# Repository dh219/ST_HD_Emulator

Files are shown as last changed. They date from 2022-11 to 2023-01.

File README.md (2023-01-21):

# ATARI ACSI Hard Drive Controller Emulator
Use your ageing ATARI ST again!

KISS principal implemented throughout!

This has been done before. I don't pretend to have invented this. However, this design uses the Raspberry PI PICO, which, at time of designing, had not been done before.

This is in know way the finished article. I have uploaded to git simply because there is some interest, and who knows? maybe others will conribute to make a "complete" package.

### Initial Release:
Both PICO CPU cores are used. Core 2 is solely used for decoding command packets. Core 1, prints command data and live status. 

Note the shell... you can do things whilst the emulator is doing its stuff. At the moment, there isn't much. Just date, time reporting. But partition dumps could be performed, partitioning and formatting sd cards etc.

Revised Hardware design
The TXB0108 part is not suitable for this project. A 74xxx245 part is needed as I used in the prototype. Why oh why did I change it !!!

### Latest Improvements:
* Incorporated local spi and sdcard files and optimised for this project.
* Removed the No-OS-FatFS dependancy.
* Two SD-CARDS are now functional.
* Tested with ICD driver, HDDriver driver, AHDI driver, PPutnik driver.
* Tested with EmuTOS and FreeMint.
Typical transfer speeds are > 900 KB/s and peak just under 1100 KB/s. Dependent upon sd-card used.





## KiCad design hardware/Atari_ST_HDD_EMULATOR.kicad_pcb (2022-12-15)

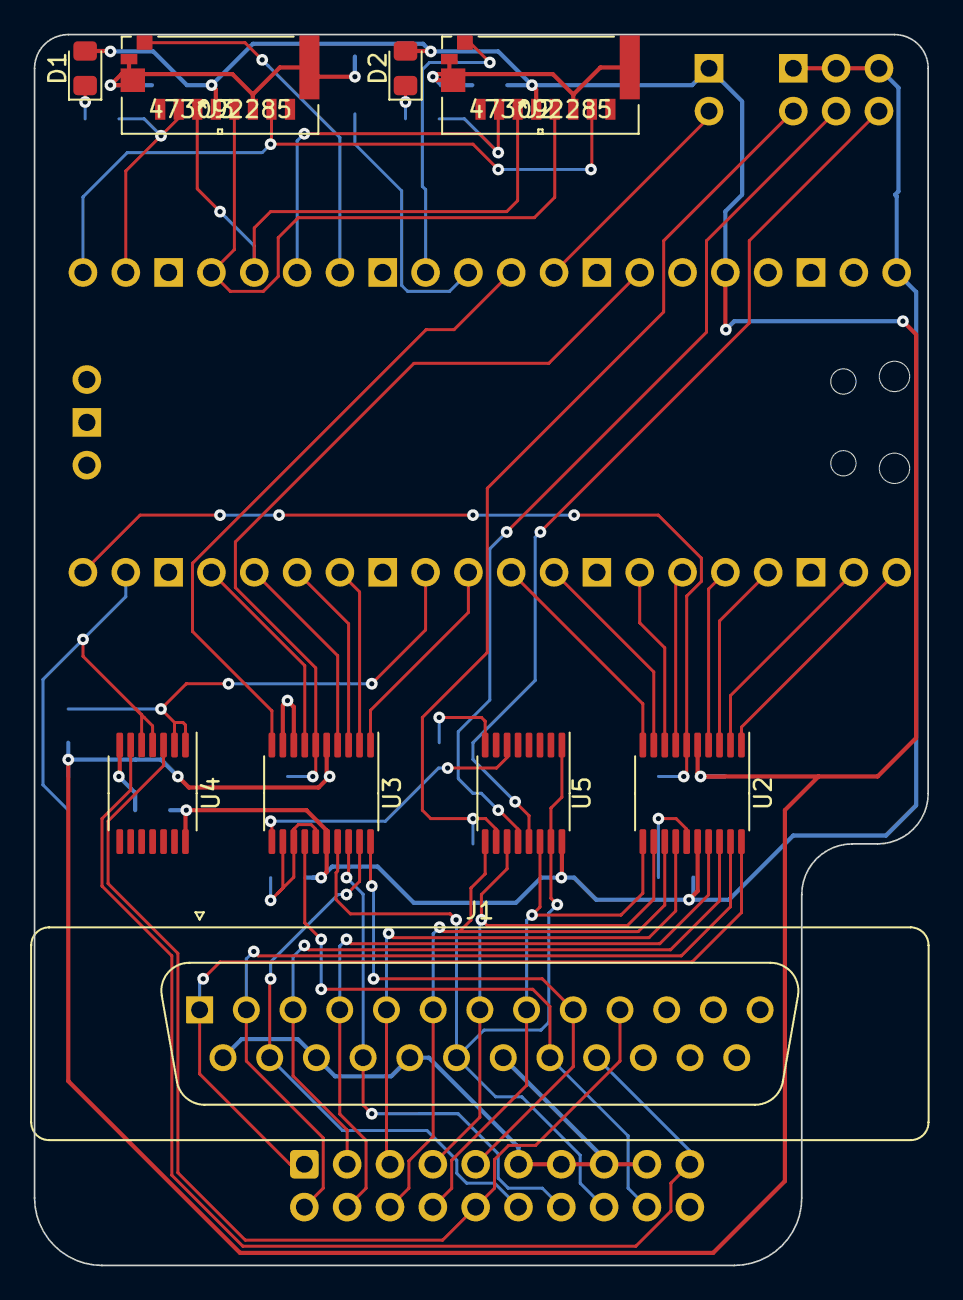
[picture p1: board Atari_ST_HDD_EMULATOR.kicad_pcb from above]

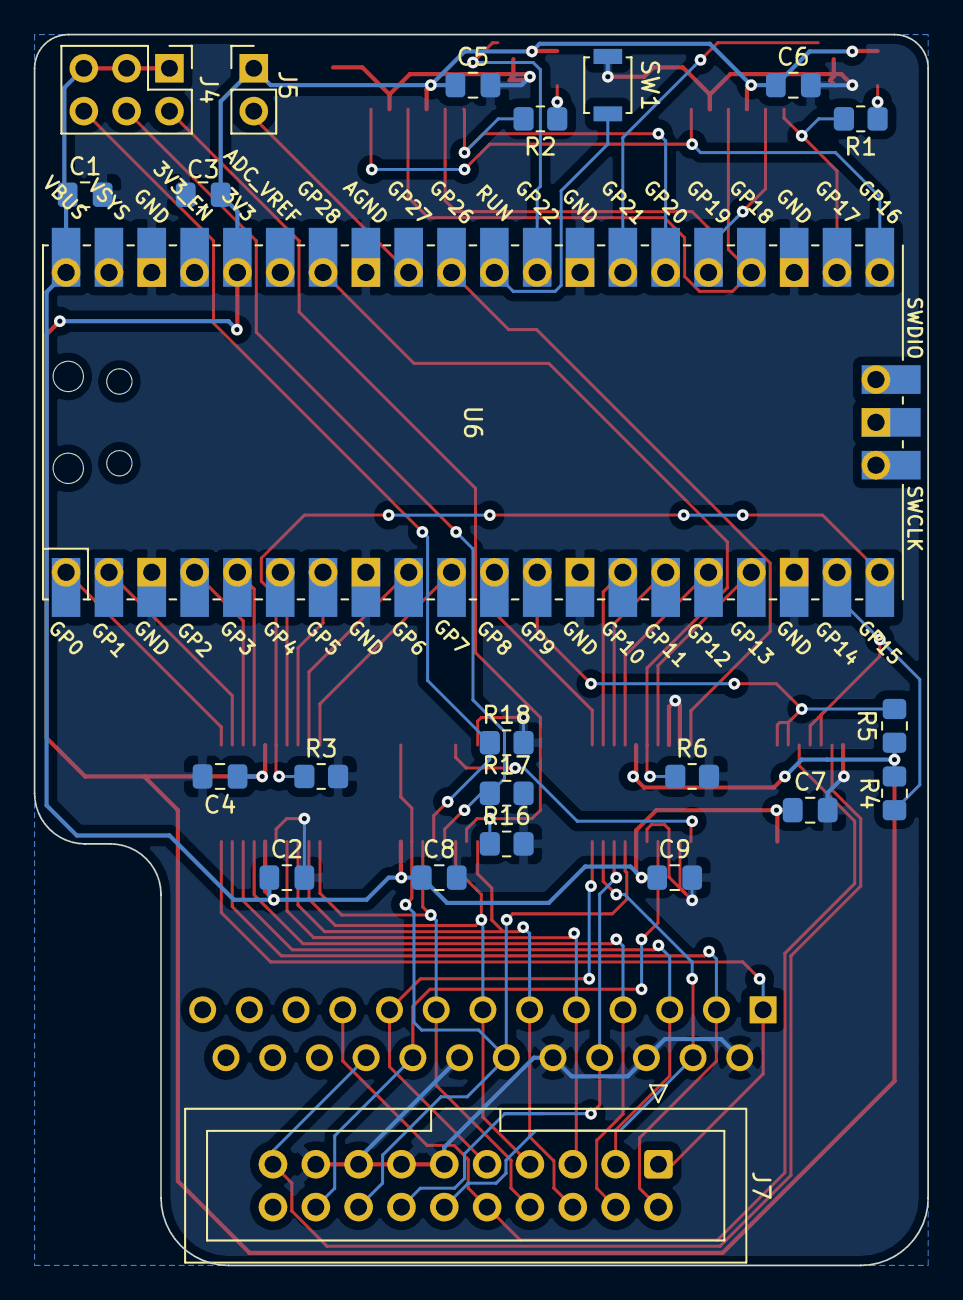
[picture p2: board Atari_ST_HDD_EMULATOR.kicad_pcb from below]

Board: 2 copper layers, 53.0 x 73.0 mm, 32 parts (23 on the bottom side), 51 nets.

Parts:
C1, C2, C3, C4, C7, C8, C9: 100nF; C_0805_2012Metric_Pad1.18x1.45mm_HandSolder
C5, C6: 1nF; C_0805_2012Metric_Pad1.18x1.45mm_HandSolder
D1, D2: LED; LED_0805_2012Metric_Pad1.15x1.40mm_HandSolder
J1: DB25_Male; DSUB-25_Male_Vertical_P2.77x2.84mm
J2, J3: 473092285; molex_47309-2285_sdcard
J4: ID Select; PinHeader_2x03_P2.54mm_Vertical
J5: RTC Enable; PinHeader_1x02_P2.54mm_Vertical
J7: IDC 20pin; IDC-Header_2x10_P2.54mm_Vertical
R1, R2: R220; R_0805_2012Metric_Pad1.20x1.40mm_HandSolder
R3, R4, R5, R6: R1K; R_0805_2012Metric_Pad1.20x1.40mm_HandSolder
R16, R17, R18: R10K; R_0805_2012Metric_Pad1.20x1.40mm_HandSolder
SW1: PICO RESET; SW_SPST_B3U-1000P
U2, U3: TXB0108PWR; TSSOP-20_4.4x6.5mm_P0.65mm
U4: 74HCT125PW; TSSOP-14_4.4x5mm_P0.65mm
U5: 74HCT85PW; TSSOP-16_4.4x5mm_P0.65mm
U6: Pico; RPi_Pico_SMD_TH

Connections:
+3V3: C3.1, C4.1, C5.1, C6.1, D1.2, D2.2, J2.P4, J3.P4, J5.1, R4.1, R5.1, U2.5, U3.5, U6.36
+5V: C1.1, C2.1, C7.1, C8.1, C9.1, J4.1, J4.3, J4.5, U2.16, U3.16, U4.14, U5.16, U6.40
/AD0: J1.1, J7.1, U2.20
/AD1: J1.2, J7.2, U2.19
/AD2: J1.3, J7.3, U2.18
/AD3: J1.4, J7.4, U2.17
/AD4: J1.5, J7.5, U2.14
/D0: U2.1, U6.1
/D1: U2.2, U6.2
/D2: U2.3, U6.4
/D3: U2.4, U6.5
/D4: U2.7, U6.6
/D5: U2.8, U6.7
/D6: U2.9, U6.9
/D7: U2.10, U6.10
A1: U3.4, U6.16
AA1: J1.19, J7.16, U3.17, U5.1, U5.15
AACK: J1.17, J7.14, U3.18
ACK: U3.3, U6.15
ACS: J1.9, J7.9, U3.20
AD5: J1.6, J7.6, U2.13, U5.9
AD6: J1.7, J7.7, U2.12, U5.11
AD7: J1.8, J7.8, U2.11, U5.14
ADRQ: J1.22, J7.19, U4.6
AIRQ: J1.10, J7.10, U4.3
ARST: J1.15, J7.12, U3.19
ARW: J1.21, J7.18, U3.14
CD0: J3.G4, U6.27
CD1: J2.G4, U6.29
CNTRLBUSENABLE: R6.1, U3.6, U6.34
CONTROLLERID: U3.11, U5.6
CS: U3.1, U6.11
CS0: J3.P2, R1.2, U6.22
CS1: J2.P2, R2.2, U6.26
DATABUSENABLE: R3.1, U2.6, U6.20
DRQ: R4.2, U4.4, U4.5, U6.19
GND: C1.2, C2.2, C3.2, C4.2, C5.2, C6.2, C7.2, C8.2, C9.2, J1.14, J1.16, J1.18, J1.20, J2.G1, J2.G2, J2.G3, J2.P6, J3.G1, J3.G2, J3.G3, J3.P6, J7.11, J7.13, J7.15, J7.17, R3.2, R6.2, R16.2, R17.2, R18.2, SW1.1, U2.15, U3.8, U3.9, U3.12, U3.13, U3.15, U4.7, U5.8, U6.3, U6.8, U6.13, U6.18, U6.23, U6.28, U6.33, U6.38
IRQ: R5.2, U4.1, U4.2, U6.12
unnamed: D1.1, R1.1
unnamed: D2.1, R2.1
unnamed: J4.2, R16.1, U5.10
unnamed: J4.4, R17.1, U5.12
unnamed: J4.6, R18.1, U5.13
PICO_RST: SW1.2, U6.30
RST: U3.2, U6.14
RTC_ENABLE: J5.2, U6.32
RW: U3.7, U6.17
SELECTED: U3.10, U6.31
SPI_CLK: J2.P5, J3.P5, U6.24
SPI_RX: J2.P7, J3.P7, U6.21
SPI_TX: J2.P3, J3.P3, U6.25

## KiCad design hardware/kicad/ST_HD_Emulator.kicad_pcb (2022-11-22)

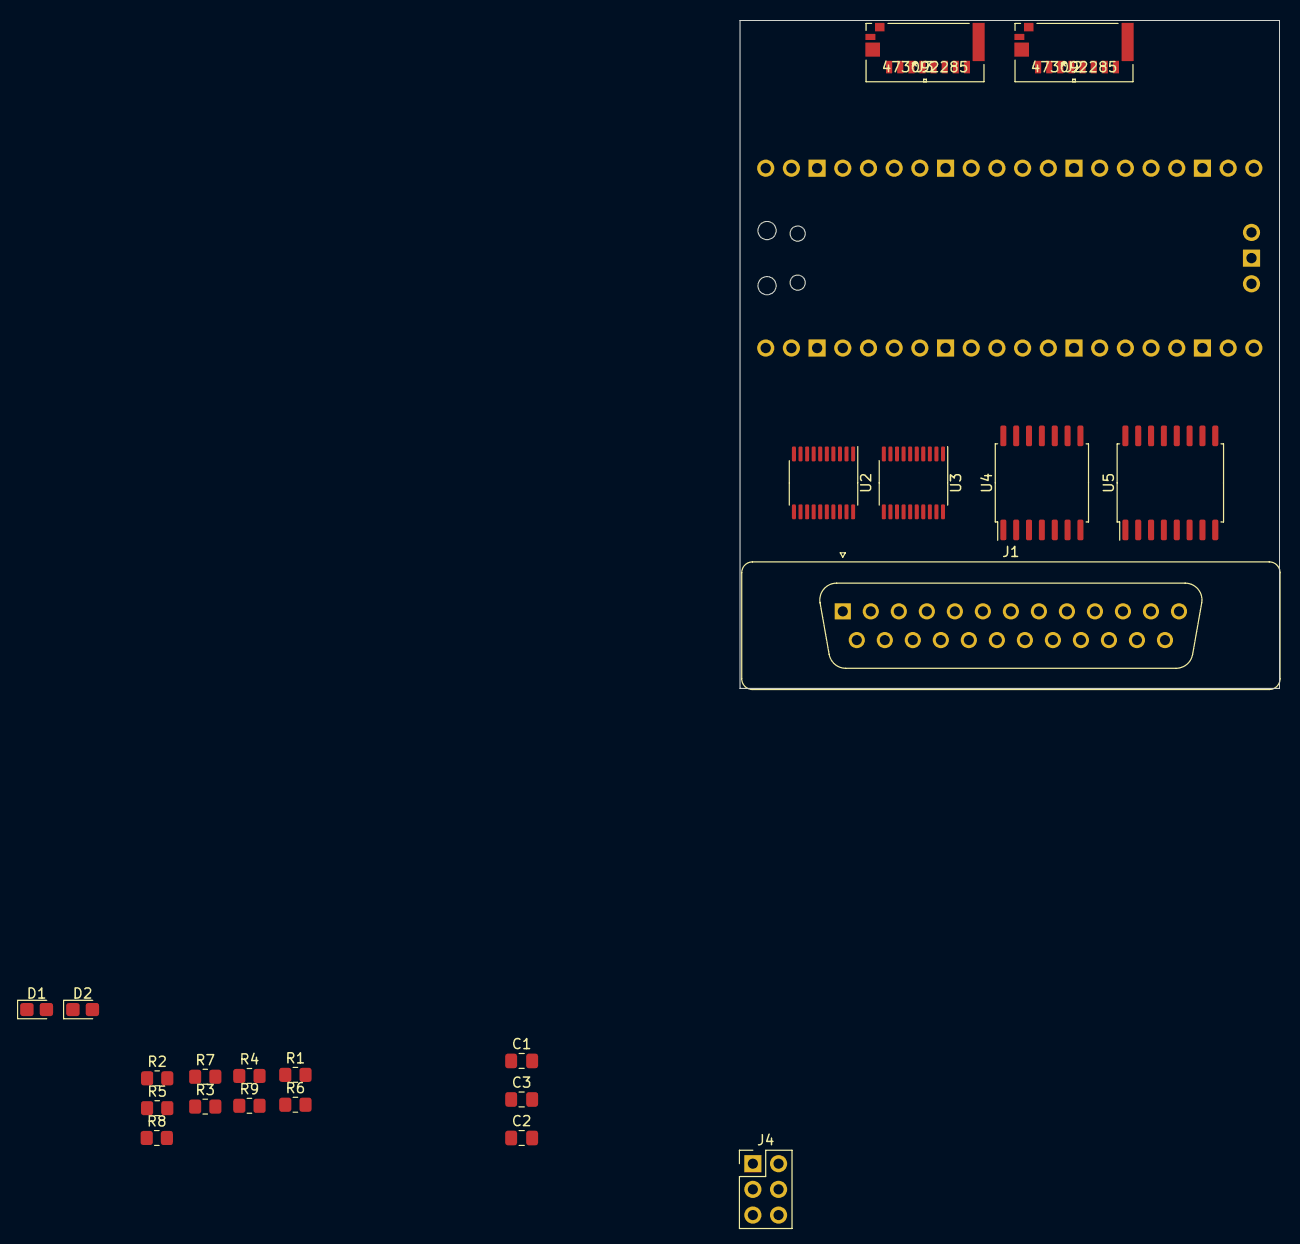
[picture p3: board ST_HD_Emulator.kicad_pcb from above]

Board: 2 copper layers, 53.3 x 66.0 mm, 23 parts (1 on the bottom side), 49 nets, no tracks yet.

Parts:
C1, C2, C3: 100nF; C_0805_2012Metric_Pad1.18x1.45mm_HandSolder
D1, D2: LED; LED_0805_2012Metric_Castellated
J1: DB25_Male; DSUB-25_Male_Vertical_P2.77x2.84mm
J2, J3: 473092285; molex_47309-2285_sdcard
J4: Controller ID Select; PinHeader_2x03_P2.54mm_Vertical
R1, R2: R220; R_0805_2012Metric_Pad1.20x1.40mm_HandSolder
R3, R4, R8, R9: R1K; R_0805_2012Metric_Pad1.20x1.40mm_HandSolder
R5, R6, R7: R10K; R_0805_2012Metric_Pad1.20x1.40mm_HandSolder
U1: Pico; RPi_Pico_SMD_TH
U2, U3: TXB0108DQSR; TSSOP-20_4.4x6.5mm_P0.65mm
U4: 74LS125; SOIC-14W_7.5x9mm_P1.27mm
U5: 74LS85; SOIC-16W_7.5x10.3mm_P1.27mm

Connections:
+3V3: C2.1, C3.1, D1.2, D2.2, J2.P4, J3.P4, U1.36, U2.5, U3.5, U3.6
+5V: C1.1, R4.1, R8.1, R9.1, U1.40, U2.16, U3.16, U4.14, U5.16
/AD0: J1.1, U2.20
/AD1: J1.2, U2.19
/AD2: J1.3, U2.18
/AD3: J1.4, U2.17
/AD4: J1.5, U2.14
/D0: U1.1, U2.1
/D1: U1.2, U2.2
/D2: U1.4, U2.3
/D3: U1.5, U2.4
/D4: U1.6, U2.7
/D5: U1.7, U2.8
/D6: U1.9, U2.9
/D7: U1.10, U2.10
A1: U1.16, U3.4
AA1: J1.19, U3.17, U5.1
AACK: J1.17, U3.18
ACK: U1.15, U3.3
ACS: J1.9, U3.20, U5.15
AD5: J1.6, U2.13, U5.14
AD6: J1.7, U2.12, U5.11
AD7: J1.8, U2.11, U5.9
ARST: J1.15, U3.19
ARW: J1.21, U3.14
CD0: J3.G4, U1.27
CD1: J2.G4, U1.29
CONTROLLERID: U3.11, U5.6
CS: U1.11, U3.1
CS0: J3.P2, R1.2, U1.22
CS1: J2.P2, R2.2, U1.26
DATABUSENABLE: R3.1, U1.20, U2.6
DRQ: R8.2, U1.19, U4.4, U4.5
GND: C1.2, C2.2, C3.2, J1.14, J1.16, J1.18, J1.20, J2.G1, J2.G2, J2.G3, J2.P6, J3.G1, J3.G2, J3.G3, J3.P6, R3.2, R5.2, R6.2, R7.2, U1.3, U1.8, U1.13, U1.18, U1.23, U1.28, U1.33, U1.38, U1.42, U2.15, U3.15, U4.7, U5.8
IRQ: R9.2, U1.12, U4.1, U4.2
unnamed: D1.1, R1.1
unnamed: D2.1, R2.1
unnamed: J1.10, U4.3
unnamed: J1.22, U4.6
unnamed: J4.1, J4.3, J4.5, R4.2
unnamed: J4.2, R7.1, U5.13
unnamed: J4.4, R6.1, U5.12
unnamed: J4.6, R5.1, U5.10
RST: U1.14, U3.2
RW: U1.17, U3.7
SELECTED: U1.31, U3.10
SPI_CLK: J2.P5, J3.P5, U1.24
SPI_RX: J2.P7, J3.P7, U1.21
SPI_TX: J2.P3, J3.P3, U1.25

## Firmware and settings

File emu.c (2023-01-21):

/*
 * ATARI ST HDC Emulator
 *
 * File:    emu.c
 * Author:  Steve Bradford
 * Created: September 2022
 * 
 * 
 * Using Raspberry PI PICO RP2040
 *
 * 
 * This Emulator is designed to be controller 0.
 * Targets 0 and 1 are assigned to SD0 and SD1.
 * Target 6 is used by the ICD RTC
 * 
 * The cpu clock is altered at initialisation to give us optimal SPI speed
 * of 33 MHz. This yields a transfer rate of just over 1 MB/s. NOTE, I 
 * have only used current 8GB/16GB/32GB micro-sd cards. I do not think 
 * older cards will work.
 * 
 * I have tested using ICD driver, and PP driver
 * FreeMintOS works okay
 * EmuTOS works okay
 * 
 * 
 */

#include <stdio.h>
#include <stdlib.h>
#include <string.h>
#include <pico/stdlib.h>
#include <pico/util/datetime.h>
#include "pico.h"
#include "hardware/rtc.h"
#include "pico/multicore.h"
#include "hardware/clocks.h"

/* project specific includes */
#include "emuerror.h"
#include "emu.h"
#include "emucmd.h"
#include "emurtc.h"
#include "shell/emushell.h"
#include "emuinit.h"



/* prototypes */
static int     getCMD   ( CommandDescriptorBlock * );
static void    doStatus ( uint8_t );
static int     rawRD    ( CommandDescriptorBlock *, DRIVES * );
static int     rawWR    ( CommandDescriptorBlock *, DRIVES * );
static uint8_t rdDMA    ( uint8_t *, uint32_t );
static uint8_t wrDMA    ( uint8_t *, uint32_t );

#ifdef DEBUG_IO
void checkIRQDRQ ( void );
void checkInputs ( void );
#endif

#if ICD_RTC
static void    processICDRTC   ( void );

#if DEBUG_ICDRTC
static void    printICDRTCbuff ( void );
volatile bool  doPrintICDRTCbuff;
#endif

uint8_t ICDRTCbuff [128];
#endif


/* 64 bytes */
uint8_t INQUIRY_DATA [] =
{
	0,                                          /* device type 0 = direct access device */
	0x80,                                       /* device type qualifier (removable) */
	2,                                          /* ACSI/SCSI version */
	2,                                          /* reserved */
	59,                                         /* length of the following data */
	0, 0, 0,                                    /* Vendor specific data */
	'B','B','a','N','-','R','P','P',            /* T10 Vendor ID    8 chars */
	' ','H','D','C',' ',' ','S','D',            /* Product ID       8 chars */
	'#',' ','#','#','#',' ','G','B',            /* Product Revision 8 chars */
	'1','.','x','x','0','0','0','0',            /* Firmware Revision (4) / Drive Serial Number (4) */
    0,0,0,0,0,0,0,0,0,0,0,0,0,0,0,0,            /* Vendor Unique - Empty */
    0,0,0,0,0,0,0,0                             /* pad to 64 bytes - ATARI FIFO needs multiples of 16 bytes */
};


uint8_t  DMAbuffer  [512 * 256];                /* max transfer size 128 KB */
DRIVES   drv        [MAX_DRIVES]; //[MAX_ID + 1];               /* IDs 0 - 6 */

uint32_t gStatus;                               /* used for printing - copy of CDB */
CommandDescriptorBlock gCDB;                    /* used for printing - copy of CDB */

#ifdef DEBUG
volatile bool       VERBOSE;                    /* enable / disable debug print */
#endif

volatile uint32_t   intState;                   /* interrupt state save/restore */
volatile bool       gotRST;
volatile bool       doPrint;
volatile datetime_t gdttm;                      /* global date time structure - update once per minute */


/*
 * run on second core
 * 
 */

void __not_in_flash_func (core1Entry) (void)
{
    CommandDescriptorBlock sCMD;


    memset ( &sCMD, 0, sizeof (CommandDescriptorBlock) );

    disableInterrupts ();                       /* no interruptions please */

    for ( int i = 0; i < MAX_DRIVES; i++ )
    {
        drv [i].locked      = false;
        drv [i].packetCount = 0;
        drv [i].ejected     = false;
        drv [i].prevState   = true;
    }

#if ICD_RTC
    emudate ( "", 0 );                          /* initialise ICD RTC date/time array */
    emutime ( "", 0 );
#endif

    gpio_set_dir_in_masked (ACSI_DATA_MASK);

#if DEBUG_IO
    //checkIRQDRQ ();
    checkInputs ();
#endif

#if PROJECT_HARDWARE
    controlBus (ENABLE);                        /* enable control bus so we can listen for commands */
    dataBus (DISABLE);
#endif

    IRQ_HI ();
    DRQ_HI ();

    /* monitor ACSI bus */
    while ( 1 ) 
    {
        /* 
         * ATARI holds RST low for 12us 
         */
   
        if ( gpio_get ( RST ) == LO )
        {
            dataBus (DISABLE);

            IRQ_HI ();
            DRQ_HI ();
            
            gpio_set_dir_in_masked (ACSI_DATA_MASK); 
#if DEBUG
            printf ( "RESET\n" );
#endif            
            waitRST ();                         // wait for RST to go high 
        }

        /* ============= */
        /* command phase */
        /* ============= */

        /* 
         * check GPIO for new command packet - A1 and RW = low
         * 
         * time critical, code MUST be kept to the minimum, otherwise, can miss bytes
         * interrupts should be disabled for the duration of the CDB building at least
         * 
         */

        if ( newCMD () ) 
        { 
            dataBus (ENABLE); 

            waitCS ();                          /* wait for CS low */
           
            sCMD.b [0] = rdDataBus ();          /* data is available to read now - byte 0 */
            
            waitRW (LO);                        /* wait for RW to go high before continuing */
            
            /* check this command is for this controller 
             * better to do in hardware with a switch selection ? */
            if ( sCMD.DEVICE.target == TARGET0 || sCMD.DEVICE.target == TARGET1 )
            {
                sCMD.cmdLength = 6;

                IRQ_LO ();                      /* assert IRQ to tell ATARI to continue */

                waitA1 ();                      /* subsequent command bytes are read whilst A1 is high */
                waitCS (); 
                IRQ_HI ();  
              
                sCMD.b [1] = rdDataBus ();      /* byte 2 - check for special/extended commands */
                
                waitRW (LO);
                                                /* we have a maximum of 12us to assert IRQ, starting....... now */

                if ( sCMD.DEVICE.opcode == 0x1f ) /* ACSI commands use 5 bits, highest ACSI command is 0x1f */
                {
                    sCMD.cmdLength = 7;         /* 6 + 1 */

                    if ( sCMD.b [1] >= 0xa0 )
                    {
                        sCMD.cmdLength = 13;    /* 12 + 1 */
                    }

                    else if ( sCMD.b [1] >= 0x80 )
                    {
                        sCMD.cmdLength = 17;    /* 16 + 1 */
                    }

                    else if ( sCMD.b [1] >= 0x20 )
                    {
                        sCMD.cmdLength = 11;    /* 10 + 1 */
                    }
                }

                IRQ_LO ();                      /* assert IRQ */

                for ( int d = 2; d < sCMD.cmdLength; d++ )
                {       
                    waitCS ();                  /* ATARI tells us another byte is ready */
                    IRQ_HI ();  
                    
                    sCMD.b [d] = rdDataBus ();  /* bytes 2-n */
                   
                    waitRW (LO);         
                                                /* the last command byte does NOT assert IRQ */
                    if ( d == (sCMD.cmdLength - 1) )
                        break;
                                      
                    IRQ_LO ();                  /* tell ATARI we are ready for next byte */
                }        

                dataBus (DISABLE);

                getCMD ( &sCMD );               /* process ACSI/SCSI command */
            }


#if ICD_RTC
#if !PROJECT_HARDWARE
            else if ( sCMD.DEVICE.target == TARGET6 && RTC_ENABLED )
            {
#else
            if ( RTC_ENABLED )
            {
#endif

                memset ( ICDRTCbuff, 0, sizeof (ICDRTCbuff) );

                ICDRTCbuff [0] = sCMD.b [0];       

                processICDRTC ();
            }
#endif
            else                                /* ignore command, it wasn't for us */
            {                                   /* ATARI will timeout */
                IRQ_HI ();
                DRQ_HI ();

                dataBus (DISABLE);              /* data-bus trisate */
            }

        } /* end of command */

    }
    
    return;
}






/* 
 * use cpu core 0 to print command status
 * optimise to reduce overheads 
 */

static inline void printCmd ( CommandDescriptorBlock *CDB, int status ) 
{    
    char cmdString [16];
    char debugLine [80];
    
    switch ( CDB->DEVICE.opcode )
    {
        case TEST_UNIT_READY:
            sprintf ( cmdString, "TEST_UNIT_READY" );
            break;
        case REQUEST_SENSE:
            sprintf ( cmdString, "REQUEST_SENSE  " );
            break;
        case FORMAT_UNIT:
            sprintf ( cmdString, "FORMAT_UNIT    " );
            break;
        case CMD_READ:
            sprintf ( cmdString, "CMD_READ       " );
            break;
        case CMD_WRITE:
            sprintf ( cmdString, "CMD_WRITE      " );
            break;
        case CMD_SEEK:
            sprintf ( cmdString, "CMD_SEEK       " );
            break;
        case VENDOR_SPECIFIC:
            sprintf ( cmdString, "VENDOR_SPECIFIC" );
            break;
        case CMD_INQUIRY:
            sprintf ( cmdString, "CMD_INQUIRY    " );
            break;
        case MODE_SELECT:
            sprintf ( cmdString, "MODE_SELECT    " );
            break;
        case MODE_SENSE:
            sprintf ( cmdString, "MODE_SENSE     " );
            break;
        case START_STOP:
            sprintf ( cmdString, "START_STOP     " );
            break;
        case MEDIA_REMOVE:
            sprintf ( cmdString, "MEDIA_REMOVE   " );
            break;
        case EXTENDED_CMD:
            sprintf ( cmdString, "EXTENDED_CMD   " );
            break;
        default:
            sprintf ( cmdString, "UNKNOWN_COMMAND" );
            break;
    }
   
    for ( int i = 0; i < CDB->cmdLength; i++ )
    {
        if ( i == 2 && CDB->cmdLength == 6 )
            sprintf ( debugLine, "%s tgt=%d lun=%d (0x%02x:%02x:%02x:", 
                    cmdString, 
                    CDB->DEVICE.target, 
                    CDB->BYTE1.lun,
                    CDB->DEVICE.opcode,
                    CDB->b [1],
                    CDB->b [2]
                    );
        
        else if ( i == 2 && CDB->cmdLength > 6 )
            sprintf ( debugLine, "%s tgt=%d lun=%d (0x%02x:%02x:%02x:", 
                    cmdString, 
                    CDB->DEVICE.target,
                    CDB->b [2] >> 5,
                    CDB->DEVICE.opcode,
                    CDB->b [1],
                    CDB->b [2]
                    );
        
        if ( i < 3 )
            continue;

        sprintf ( debugLine + strlen (debugLine), "%02x:", CDB->b [i] );
    }

    sprintf ( debugLine + strlen (debugLine), "\b \b) (%02x)\n", status );
    
    printf ( debugLine );                       /* one printf to stdio */
}



int main ( void )
{
    datetime_t dt;
    char datetime_buf [80];


    EMUinit ();                                 /* MUST do first */
    rtc_init ();
    buildDateTime ();                           /* use compilation date/time to initialise RTC */

    printf ( "%s\n", TITLE );
    printf ( "Controller ID %d\n", CONTROLLER_ID );
    printf ( "Hardware initialised\n" );
    printf ( "RTC Jumper is %s\n", gpio_get (RTC_ENABLED) ? "ON" : "OFF" );
    printf ( "CPU clock is running at %d MHz\n\n", clock_get_hz (clk_sys) / 1000000 );

    printf ( "ACSI HDC Emulator Running ... press ESC for shell\n\n" );
    

#ifdef DEBUG
    VERBOSE = true;
#endif

    doPrint = false;                            /* flag to show if debug print is needed */

#if ICD_RTC && DEBUG_ICDRTC
    doPrintICDRTCbuff = false;
#endif

    sleep_ms (1000);

    multicore_launch_core1 ( core1Entry );      /* one whole cpu dedicated to decoding commands etc. */

    gpio_put ( ONBOARD_LED, HI );               /* show we are initialised and running */

    mountRAW (0);                               /* initialise disks */
    mountRAW (1);
    
    /* 
     * do something in core 0 :) 
     */
    while ( true ) 
    {
#if !DEBUG
        printf ( "\033[2J" );

        status ();

        rtc_get_datetime (&dt);
        datetime_to_str  ( datetime_buf, sizeof (datetime_buf), &dt );
        printf ( "\n%s\n", datetime_buf );

        sleep_ms (1000);
#else
        /* do the debug print on this core to reduce overheads on other core */
        if ( doPrint && VERBOSE )
        {
            doPrint = false;

            printCmd ( &gCDB, gStatus );
        }
#endif

#if ICD_RTC && DEBUG_ICDRTC
        if ( doPrintICDRTCbuff )
        {
            doPrintICDRTCbuff = false;

            printICDRTCbuff ();
        }
#endif

        /* enter shell on ESC key */
        if ( getchar_timeout_us (0) == 0x1b )
        {
            doShell ();                         /* all the time we are in the shell, we are not checking for sd card removal/insertion */
        }

        checkSDcards ();                        /* check sd cards insertion state */
    }

    return 0;
}



static inline int __not_in_flash_func (getCMD) ( CommandDescriptorBlock *CDB )
{  
    register uint8_t LUN;
    register uint8_t TARGET;
    DRIVES  *pdrv;
   

    /* ============= */
    /* data phase    */
    /* ============= */

    TARGET = CDB->DEVICE.target;

    if ( CDB->cmdLength == 6 )
        LUN = CDB->BYTE1.lun; 

    else
        LUN = CDB-> b [2] >> 5;

    pdrv    = &drv [TARGET - CONTROLLER_ID];    /* max of 2 disks 0, 1 */

    pdrv->packetCount += 1;                     /* increment packet counter for this drive - just for stats */

    switch ( CDB->DEVICE.opcode ) {

        case TEST_UNIT_READY:        
            /* 
                * 0x00 No error 
                * 0x04 Device not ready 
                * 0x30 Controller self test failed
                * 
                * The check condition bit (1) should be set if error
                * 
                * NOTE status byte bits 5-7 = controller number
                */
            pdrv->status = pdrv->pSD->mounted ? ERR_DRV_NO_ERROR : CHECK_CONDITION;

            if ( pdrv->status )
            {
                pdrv->lastError.SK   = SCSI_SK_NOT_READY;
                pdrv->lastError.ASC  = SCSI_ASC_MEDIUM_NOT_PRESENT;
                pdrv->lastError.ASCQ = SCSI_ASCQ_NO_ADDITIONAL_SENSE_INFORMATION;
            }

            else
            {
                pdrv->lastError.SK   = SCSI_SK_NO_SENSE;
                pdrv->lastError.ASC  = SCSI_ASC_NO_ADDITIONAL_SENSE;
                pdrv->lastError.ASCQ = SCSI_ASCQ_NO_ADDITIONAL_SENSE_INFORMATION;
            }

            break;

        /* SCSI SPC-5 */
        case REQUEST_SENSE:
            memset ( DMAbuffer, 0, CDB->len );

            /* should the VALID bit be set ??? = 0x80 | CDB->b [1] */
            if ( CDB->b [1] & 0x01 )            /* check descriptor bit 0 = fixed format sense data, 1 = descriptor format sense data */
                DMAbuffer [0] = 0x72;           /* Response Code (byte 0) = Current Information DESCRIPTOR */  

            else
                DMAbuffer [0] = 0x70;           /* Response Code (byte 0) = Current Information FIXED */   

            DMAbuffer [1] = 0;                  /* Reserved */
            DMAbuffer [2] = 0;                  /* FILEMARK, EOM, ILI, SDAT_OVFL, bits 0-3 sense key */
            DMAbuffer [3] = 0;                  /* Information field - bytes 3 (MSB), 4, 5, 6 (LSB) */
            DMAbuffer [7] = 12;                 /* additional sense length (n-7) */

           
            /* sense data */
            /* 0 - descriptor type
             *     0x00 information sense, 
             *     0x01 command specific, 
             *     0x02 sense key, 
             *     0x03 field replacable unit, 
             *     0x0a another progress indication, 
             *     0x0c foreward sense, 
             *     0x0e device designation, 
             *     0x0f microcode activation, 
             *     0x80-0xff vendor specific
             */

            /* Information Sense */
            DMAbuffer [8]  = 0;                 /* byte 0 descriptor type */
            DMAbuffer [9]  = 0x0a;              /* byte 1 additional length */
            DMAbuffer [10] = 0x80;              /* byte 2 reserved - set valid bit if FIXED */
            DMAbuffer [11] = 0;                 /* byte 3 reserved */
            DMAbuffer [12] = pdrv->lastError.ASC;  /* Additional Sense Code */
            DMAbuffer [13] = pdrv->lastError.ASCQ; /* Additional Sense Code Qualifier */
            DMAbuffer [14] = 0;                 /* Field replacable unit code */
            DMAbuffer [15] = 0;                 /* sense key specific information 15, 16, 17 */
            DMAbuffer [16] = 0;
            DMAbuffer [17] = 0;
            DMAbuffer [18] = 0;                 /* additional sense bytes 18..n */
            DMAbuffer [19] = 0;               
                
            switch ( pdrv->lastStatus )
            {
                case ERR_DRV_NO_ERROR: 
                    DMAbuffer [2] |= SCSI_SK_NO_SENSE; 
                    break;
                case ERR_CMD_INVALID_CMD:
                case ERR_CMD_INVALID_ADD:
                case ERR_CMD_INVALID_ARG:
                case ERR_CMD_INVALID_DRV:
                    DMAbuffer [2] |= SCSI_SK_ILLEGAL_REQUEST; 
                    break;

                default: 
                    DMAbuffer [2] |= SCSI_SK_HARDWARE_ERROR; 
                    break;
            }
               
            pdrv->status = ERR_DRV_NO_ERROR;

            wrDMA ( DMAbuffer, 20 );            /* need to do doStatus () ASAP after a wrDMA () */

            break;

        case FORMAT_UNIT:
            pdrv->status = ERR_DRV_NO_ERROR;
           
            if ( ! pdrv->pSD->mounted )
            {
                pdrv->lastError.status = SCSI_ERR_INV_LUN;
                pdrv->status           = ERR_CMD_INVALID_DRV;
            }

            else
            {
                sd_erase ( pdrv->pSD );
            }

            break;

        case CMD_READ:
            if ( ! pdrv->pSD->mounted || LUN != 0 )
            {
                pdrv->lastError.SK     = SCSI_SK_NOT_READY;
                pdrv->lastError.ASC    = SCSI_ASC_MEDIUM_NOT_PRESENT;
                pdrv->lastError.ASCQ   = SCSI_ASCQ_NO_ADDITIONAL_SENSE_INFORMATION;
                pdrv->status           = ERR_DRV_DRV_NOT_READY;
            }

            else 
            {
                pdrv->lba = (uint32_t)CDB->BYTE1.msbLBA << 16 | (uint32_t)CDB->mid << 8 | CDB->lsb;
               
                rawRD ( CDB, pdrv );
            }
        
            break;

        case CMD_WRITE:            
            if ( ! pdrv->pSD->mounted || LUN != 0 ) 
            {
                pdrv->lastError.SK     = SCSI_SK_NOT_READY;
                pdrv->lastError.ASC    = SCSI_ASC_MEDIUM_NOT_PRESENT;
                pdrv->lastError.ASCQ   = SCSI_ASCQ_NO_ADDITIONAL_SENSE_INFORMATION;
                pdrv->status           = ERR_DRV_DRV_NOT_READY;
            }

            else 
            {
                pdrv->lba = (uint32_t)CDB->BYTE1.msbLBA << 16 | (uint32_t)CDB->mid << 8 | CDB->lsb;

                rawWR ( CDB, pdrv );
            }

            break;

        /* don't need this command */
        case CMD_SEEK:
            pdrv->lastError.status = SCSI_ERR_OK;
            pdrv->status           = ERR_DRV_NO_ERROR;

            pdrv->lba  = (uint32_t)CDB->BYTE1.msbLBA << 16;
            pdrv->lba |= (uint32_t)CDB->mid << 8;
            pdrv->lba |= CDB->lsb;
            
            break;


        case CMD_INQUIRY:
            pdrv->lastError.status = SCSI_ERR_OK; 
            pdrv->status           = ERR_DRV_NO_ERROR;
               
            memcpy ( DMAbuffer, INQUIRY_DATA, sizeof (INQUIRY_DATA) );

            {
                char num [9];
                int diskSize = (float)((float)(pdrv->pSD->sectors * 512) / 1000.0 / 1000.0 / 1000.0) + 0.5;

                sprintf ( num, "%3d", diskSize );                

                DMAbuffer [24] = '0' + (TARGET - CONTROLLER_ID);  /* alter the disk number in product revision field */
                DMAbuffer [26] = num [0];
                DMAbuffer [27] = num [1];
                DMAbuffer [28] = num [2];
                DMAbuffer [29] = ' ';
                DMAbuffer [30] = 'G';
                DMAbuffer [31] = 'B';

                memcpy ( &DMAbuffer [32], VERSION, 4 );         /* include firmware revision */

                DMAbuffer [39] = '0' + (TARGET - CONTROLLER_ID);/* alter drive serial number */
                DMAbuffer [0] = 0x00;       /* device connected and is a direct access block device */

                if ( LUN != 0 )
                    DMAbuffer [0] = 0x7f;       /* this is causing me problems ??? hangs bus */
            }

            if ( CDB->len < 64 )
                DMAbuffer [4] = CDB->len - 5;
                
            wrDMA ( DMAbuffer, CDB->len );

            break;

        /* 
         * non-ACSI, 
         * SCSI commands or vendor specific ... 
         */
        default:

            switch ( CDB->DEVICE.opcode )
            {
                case START_STOP:
                    pdrv->status         = CHECK_CONDITION;
                    pdrv->lastError.SK   = SCSI_SK_NOT_READY;
                    pdrv->lastError.ASC  = SCSI_ASC_LUN_NOT_READY;
                    pdrv->lastError.ASCQ = SCSI_ASCQ_NO_ADDITIONAL_SENSE_INFORMATION;

                    break;

                case READ_BLOCK_LIMITS:
                    pdrv->status = ERR_DRV_NO_ERROR;

                    break;
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

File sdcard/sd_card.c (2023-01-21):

/* sd_card.c
Copyright 2021 Carl John Kugler III

Licensed under the Apache License, Version 2.0 (the License); you may not use
this file except in compliance with the License. You may obtain a copy of the
License at

   http://www.apache.org/licenses/LICENSE-2.0
Unless required by applicable law or agreed to in writing, software distributed
under the License is distributed on an AS IS BASIS, WITHOUT WARRANTIES OR
CONDITIONS OF ANY KIND, either express or implied. See the License for the
specific language governing permissions and limitations under the License.
*/
/*
 * This code borrows heavily from the Mbed SDBlockDevice:
 *       https://os.mbed.com/docs/mbed-os/v5.15/apis/sdblockdevice.html
 *       mbed-os/components/storage/blockdevice/COMPONENT_SD/SDBlockDevice.cpp
 *
 * Editor: Carl Kugler (carlk3@gmail.com)
 *
 * Remember your ABCs: "Always Be Cobbling!"
 */

/* mbed Microcontroller Library
 * Copyright (c) 2006-2013 ARM Limited
 *
 * Licensed under the Apache License, Version 2.0 (the "License");
 * you may not use this file except in compliance with the License.
 * You may obtain a copy of the License at
 *
 *     http://www.apache.org/licenses/LICENSE-2.0
 *
 * Unless required by applicable law or agreed to in writing, software
 * distributed under the License is distributed on an "AS IS" BASIS,
 * WITHOUT WARRANTIES OR CONDITIONS OF ANY KIND, either express or implied.
 * See the License for the specific language governing permissions and
 * limitations under the License.
 */

/* Introduction
 * ------------
 * SD and MMC cards support a number of interfaces, but common to them all
 * is one based on SPI. Since we already have the mbed SPI Interface, it will
 * be used for SD cards.
 *
 * The main reference I'm using is Chapter 7, "SPI Mode" of:
 *  http://www.sdcard.org/developers/tech/sdcard/pls/Simplified_Physical_Layer_Spec.pdf
 *
 * SPI Startup
 * -----------
 * The SD card powers up in SD mode. The start-up procedure is complicated
 * by the requirement to support older SDCards in a backwards compatible
 * way with the new higher capacity variants SDHC and SDHC.
 *
 * The following figures from the specification with associated text describe
 * the SPI mode initialisation process:
 *  - Figure 7-1: SD Memory Card State Diagram (SPI mode)
 *  - Figure 7-2: SPI Mode Initialization Flow
 *
 * Firstly, a low initial clock should be selected (in the range of 100-
 * 400kHZ). After initialisation has been completed, the switch to a
 * higher clock speed can be made (e.g. 1MHz). Newer cards will support
 * higher speeds than the default _transfer_sck defined here.
 *
 * Next, note the following from the SDCard specification (note to
 * Figure 7-1):
 *
 *  In any of the cases CMD1 is not recommended because it may be difficult for
 * the host to distinguish between MultiMediaCard and SD Memory Card
 *
 * Hence CMD1 is not used for the initialisation sequence.
 *
 * The SPI interface mode is selected by asserting CS low and sending the
 * reset command (CMD0). The card will respond with a (R1) response.
 * In practice many cards initially respond with 0xff or invalid data
 * which is ignored. Data is read until a valid response is received
 * or the number of re-reads has exceeded a maximim count. If a valid
 * response is not received then the CMD0 can be retried. This
 * has been found to successfully initialise cards where the SPI master
 * (on MCU) has been reset but the SDCard has not, so the first
 * CMD0 may be lost.
 *
 * CMD8 is optionally sent to determine the voltage range supported, and
 * indirectly determine whether it is a version 1.x SD/non-SD card or
 * version 2.x. I'll just ignore this for now.
 *
 * ACMD41 is repeatedly issued to initialise the card, until "in idle"
 * (bit 0) of the R1 response goes to '0', indicating it is initialised.
 *
 * You should also indicate whether the host supports High Capicity cards,
 * and check whether the card is high capacity - i'll also ignore this.
 *
 * SPI Protocol
 * ------------
 * The SD SPI protocol is based on transactions made up of 8-bit words, with
 * the host starting every bus transaction by asserting the CS signal low. The
 * card always responds to commands, data blocks and errors.
 *
 * The protocol supports a CRC, but by default it is off (except for the
 * first reset CMD0, where the CRC can just be pre-calculated, and CMD8)
 * I'll leave the CRC off I think!
 *
 * Standard capacity cards have variable data block sizes, whereas High
 * Capacity cards fix the size of data block to 512 bytes. I'll therefore
 * just always use the Standard Capacity cards with a block size of 512 bytes.
 * This is set with CMD16.
 *
 * You can read and write single blocks (CMD17, CMD25) or multiple blocks
 * (CMD18, CMD25). For simplicity, I'll just use single block accesses. When
 * the card gets a read command, it responds with a response token, and then
 * a data token or an error.
 *
 * SPI Command Format
 * ------------------
 * Commands are 6-bytes long, containing the command, 32-bit argument, and CRC.
 *
 * +---------------+------------+------------+-----------+----------+--------------+
 * | 01 | cmd[5:0] | arg[31:24] | arg[23:16] | arg[15:8] | arg[7:0] | crc[6:0] |
 * 1 |
 * +---------------+------------+------------+-----------+----------+--------------+
 *
 * As I'm not using CRC, I can fix that byte to what is needed for CMD0 (0x95)
 *
 * All Application Specific commands shall be preceded with APP_CMD (CMD55).
 *
 * SPI Response Format
 * -------------------
 * The main response format (R1) is a status byte (normally zero). Key flags:
 *  idle - 1 if the card is in an idle state/initialising
 *  cmd  - 1 if an illegal command code was detected
 *
 *    +-------------------------------------------------+
 * R1 | 0 | arg | addr | seq | crc | cmd | erase | idle |
 *    +-------------------------------------------------+
 *
 * R1b is the same, except it is followed by a busy signal (zeros) until
 * the first non-zero byte when it is ready again.
 *
 * Data Response Token
 * -------------------
 * Every data block written to the card is acknowledged by a byte
 * response token
 *
 * +----------------------+
 * | xxx | 0 | status | 1 |
 * +----------------------+
 *              010 - OK!
 *              101 - CRC Error
 *              110 - Write Error
 *
 * Single Block Read and Write
 * ---------------------------
 *
 * Block transfers have a byte header, followed by the data, followed
 * by a 16-bit CRC. In our case, the data will always be 512 bytes.
 *
 * +------+---------+---------+- -  - -+---------+-----------+----------+
 * | 0xFE | data[0] | data[1] |        | data[n] | crc[15:8] | crc[7:0] |
 * +------+---------+---------+- -  - -+---------+-----------+----------+
 */

/* Standard includes. */
#include <stdio.h>
#include <inttypes.h>
#include <string.h>
#include "hw_config.h"  // Hardware Configuration of the SPI and SD Card "objects"
#include "./sd_spi.h"
#include "./sd_card.h"
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

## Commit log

2022-11-22 Started initial board layout
    [ST_HD_Emulator.kicad_pcb, ST_HD_Emulator.sch]
2022-12-05 First recorded segment done
    [Atari_ST_HDD_EMULATOR.kicad_pcb, Atari_ST_HDD_EMULATOR.sch]
2022-12-15 Changed schematic to reflect different pinout of PWR package on the TX0108. PCB design needs changing
    [Atari_ST_HDD_EMULATOR.kicad_pcb, Atari_ST_HDD_EMULATOR.sch]

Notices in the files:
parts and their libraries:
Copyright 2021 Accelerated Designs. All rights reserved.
